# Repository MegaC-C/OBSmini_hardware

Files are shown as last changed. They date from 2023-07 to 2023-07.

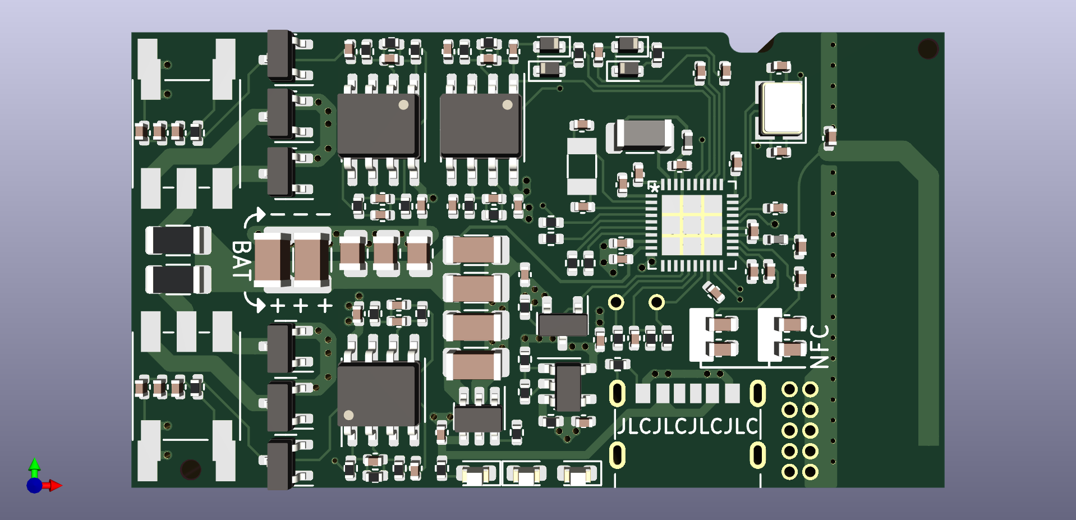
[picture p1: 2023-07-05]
OBSmini_PCB/OBSmini_PCB_TOP.png

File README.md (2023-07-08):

# OBSmini Hardware
This repository includes all the essential PCB and 3D printing files required for the OBSmini hardware.

## PCB

The Bill of Materials (BOM) and layout take inspiration from the reference designs mentioned in the schematic. 
However, they are primarily optimized for availability and cost-effectiveness, particularly for assembly services provided by JLCPCB.

"Basic Parts" are utilized whenever tolerances permit, while "Extended Parts" are employed only when absolutely necessary.

5 PCBs cost 50€ (including parts, assembly and shipping).

[OBSmini_Schematic.pdf](https://github.com/MegaC-C/OBSmini_hardware/files/11957442/OBSmini_PCB.pdf)

OBSmini_PCB_TOP
OBSmini_PCB_BOTTOM

## NFC Antenna PCB

This is simply a PCB antenna tuned to the NFC pins of the nRF52833.

NFC_PCB_antenna

## 3D Printed Case

Fusion 360 Project and three .stl files of OBSmini Case (Top, Spacer, Bottom).



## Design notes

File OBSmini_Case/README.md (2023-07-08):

Fusion 360 Project and three .stl files of OBSmini Case.



.
.
.

(also includes optional solder helper)



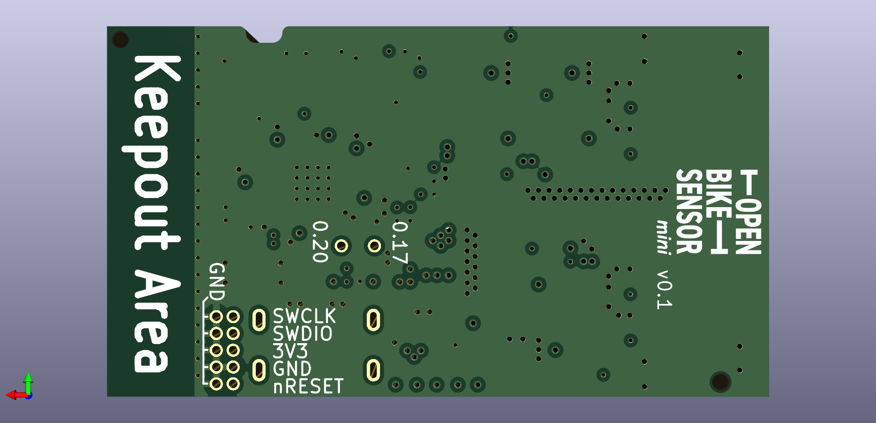
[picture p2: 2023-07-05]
OBSmini_PCB/OBSmini_PCB_BOTTOM.png

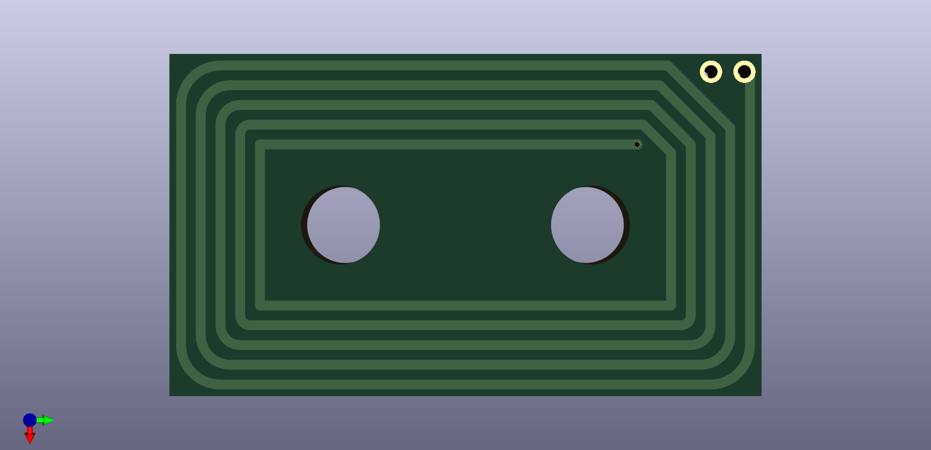
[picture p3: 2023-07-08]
OBSmini_NFC_Antenna_PCB/OBSmini_NFC_Antenna_PCB.png

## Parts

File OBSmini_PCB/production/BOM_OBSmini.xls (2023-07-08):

Comment | Designator | Footprint | JLCPCB Part #
TP4057 | U2 | TSOT-23-6 | C12044
3.3k | R309,R313,R319,R320,R323,R326 | 0402 | C25890
330 | R329 | 0402 | C25104
120k | R318,R325 | 0402 | C25750
4.7k | R303,R304 | 0402 | C25900
10k | R8 | 0402 | C25744
RB521S30T5G | D303,D304,D305,D306 | D_SOD-523 | C896535
10uH | L3 | 1206 | C1051
Q13FC1350000400 | Y2 | Crystal_SMD_3215-2Pin_3.2x1.5mm | C32346
100uF | C304,C305,C323,C324,C325,C333 | 1206 | C15008
68k | R310,R321,R322,R327 | 0402 | C36871
100pFC0G | C18,C19,C21,C22 | 0603 | C14858
USB_C_Receptacle_PowerOnly_6P | J1 | USB_C_SHOU-HAN-TYPE-C-6P | C668623
1pF | C3,C4,C9 | 0402 | C1550
3.9nH | L1 | 0402 | C14033
LED_blue | D4 | 0603 | C72041
AO3401A | Q305 | SOT-23 | C15127
LED_red | D1,D3 | 0603 | C2286
4.7uF | C14,C17,C308,C309,C315,C322,C328,C337,C6 | 0402 | C23733
33k | R305,R306 | 0402 | C25779
47uF | C334,C335,C336 | 0805 | C16780
20pFC0G | C20,C23 | 0402 | C1554
22pF | C314,C320,C327,C332 | 0402 | C1555
12pF | C1,C15,C16,C2 | 0402 | C1547
1.0uF | C12,C13 | 0402 | C52923
X322532MOB4SI | Y1 | Crystal_SMD_3225-4Pin_3.2x2.5mm | C9009
100pF | C10 | 0402 | C1546
1k | R2,R308,R317,R6,R7 | 0402 | C11702
6.8nF | C302,C306,C307,C310,C311,C313,C319,C321 | 0402 | C1542
1 | R301,R302 | 1206 | C17928
AO3400A | Q301,Q302,Q303,Q304 | SOT-23 | C20917
100nF | C11,C26,C5,C7 | 0402 | C307331
2k | R3 | 0402 | C4109
1M | R1,R307,R311,R312,R314,R328 | 0402 | C26083
220pF | C316,C317,C329,C330 | 0402 | C1530
LMV321 | U304 | SOT-23-5 | C7972
1nF | C312,C318,C326,C331,C8 | 0402 | C1523
10nF | C301,C303 | 0402 | C15195
15nH | L4 | 0402 | C27143
MCP6002T | U301,U302,U303 | SOIC-8_3.9x4.9mm_P1.27mm | C7377
20k | R316,R324 | 0402 | C25765
NRF52833-QDAA | U1 | NRF52833-QDAA-R7 | C2895249
BAV99 | D301,D302 | SOT-23 | C2500

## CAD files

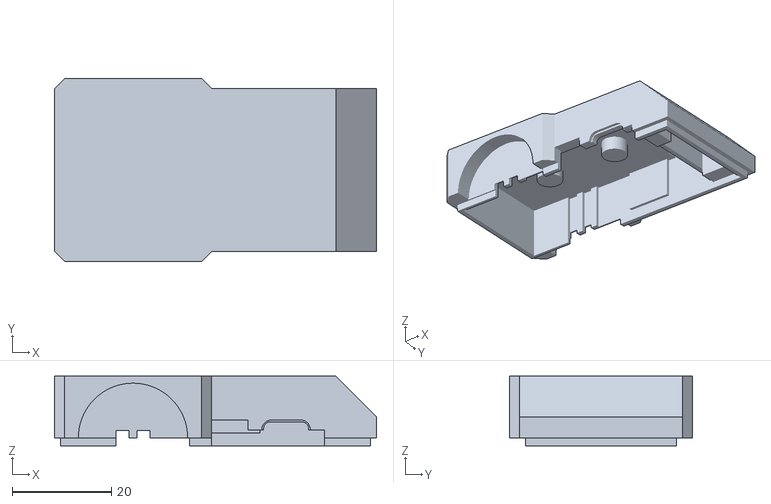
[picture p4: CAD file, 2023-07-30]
OBSmini_Case/OBSmini_Case_Top_with_WindowLED.stl
64.8 x 36.8 x 14.0

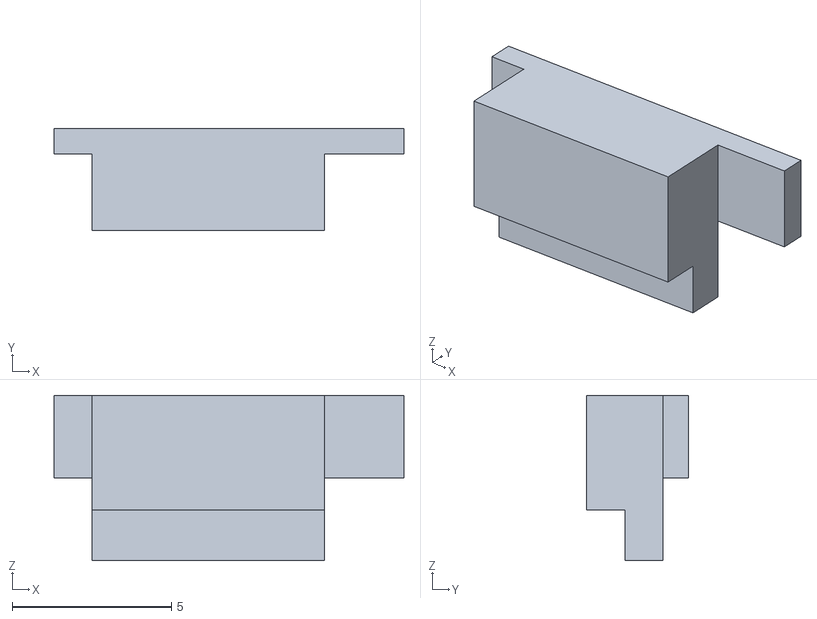
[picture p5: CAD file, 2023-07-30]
OBSmini_Case/OBSmini_Case_WindowLED.stl
11.0 x 3.20 x 5.20

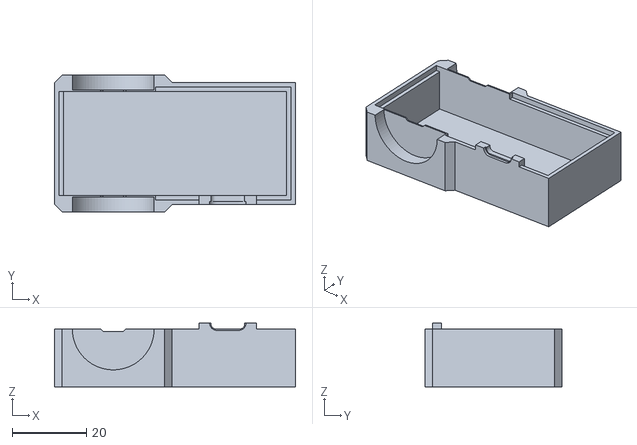
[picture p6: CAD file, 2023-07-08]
OBSmini_Case/OBSmini_Case_Bottom.stl
64.8 x 36.8 x 17.2

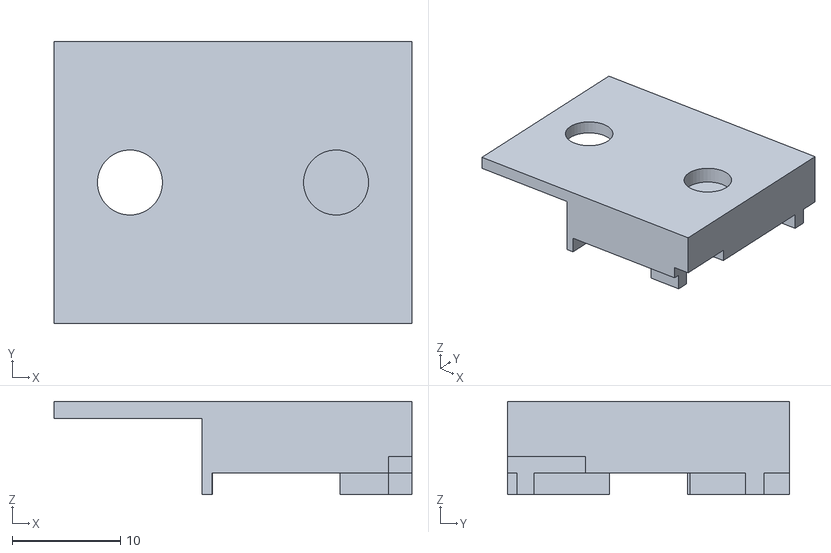
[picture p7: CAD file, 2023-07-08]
OBSmini_Case/OBSmini_Case_Spacer.stl
33.0 x 26.0 x 8.60

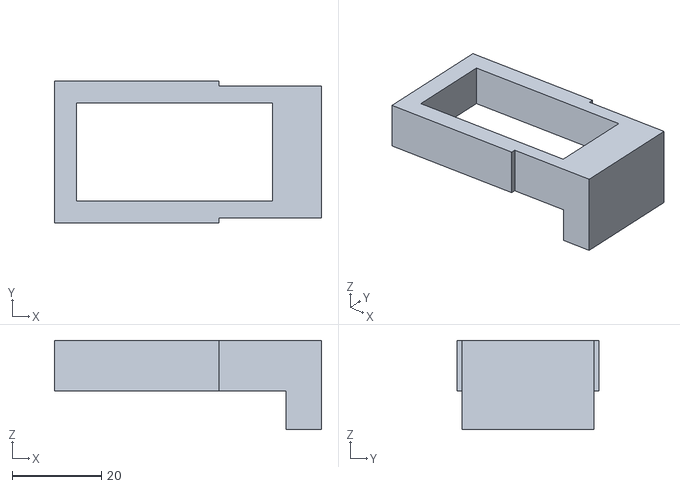
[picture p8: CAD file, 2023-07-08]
OBSmini_Case/OBSmini_solderHelper.stl
60.0 x 32.0 x 20.0

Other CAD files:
OBSmini_Case/OBSmini_Case_Top_without_WindowLED.stl
OBSmini_Case/OBSmini_Case.f3d

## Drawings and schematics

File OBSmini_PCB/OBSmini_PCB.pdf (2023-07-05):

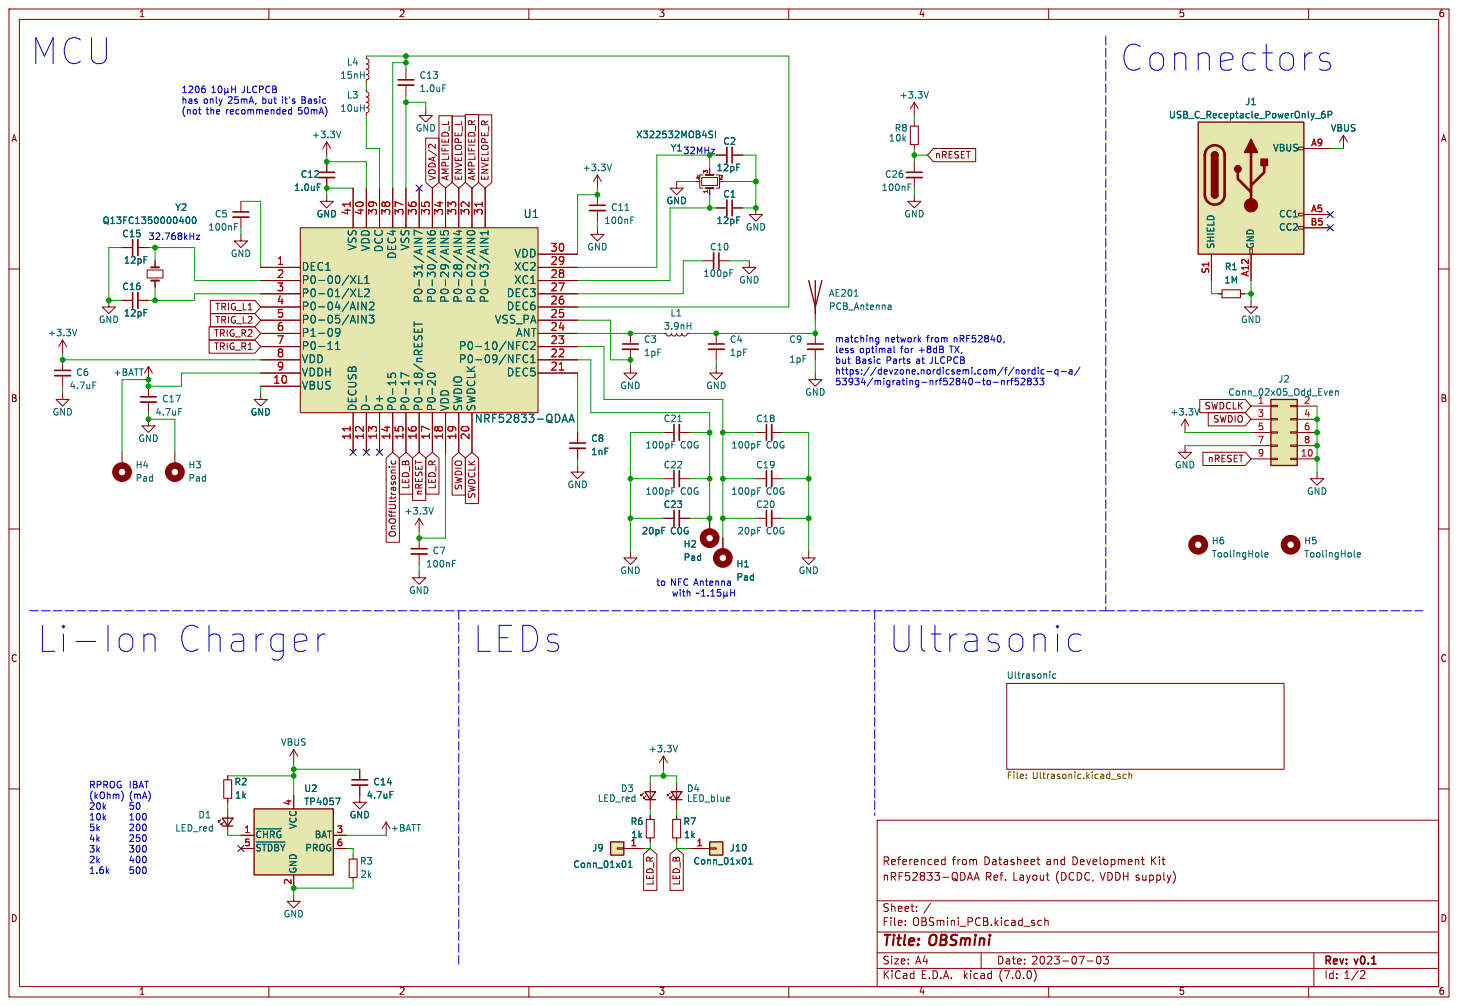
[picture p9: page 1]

32MHz 1206 þÿ10µHJLCPCB
has only 25mA, but it's Basic

matching network from nRF52840,
less optimal for +8dB TX, but Basic Parts at JLCPCB

https://devzone.nordicsemi.com/f/nordic-q-a/

to NFC Antenna with þÿ~1.15µH

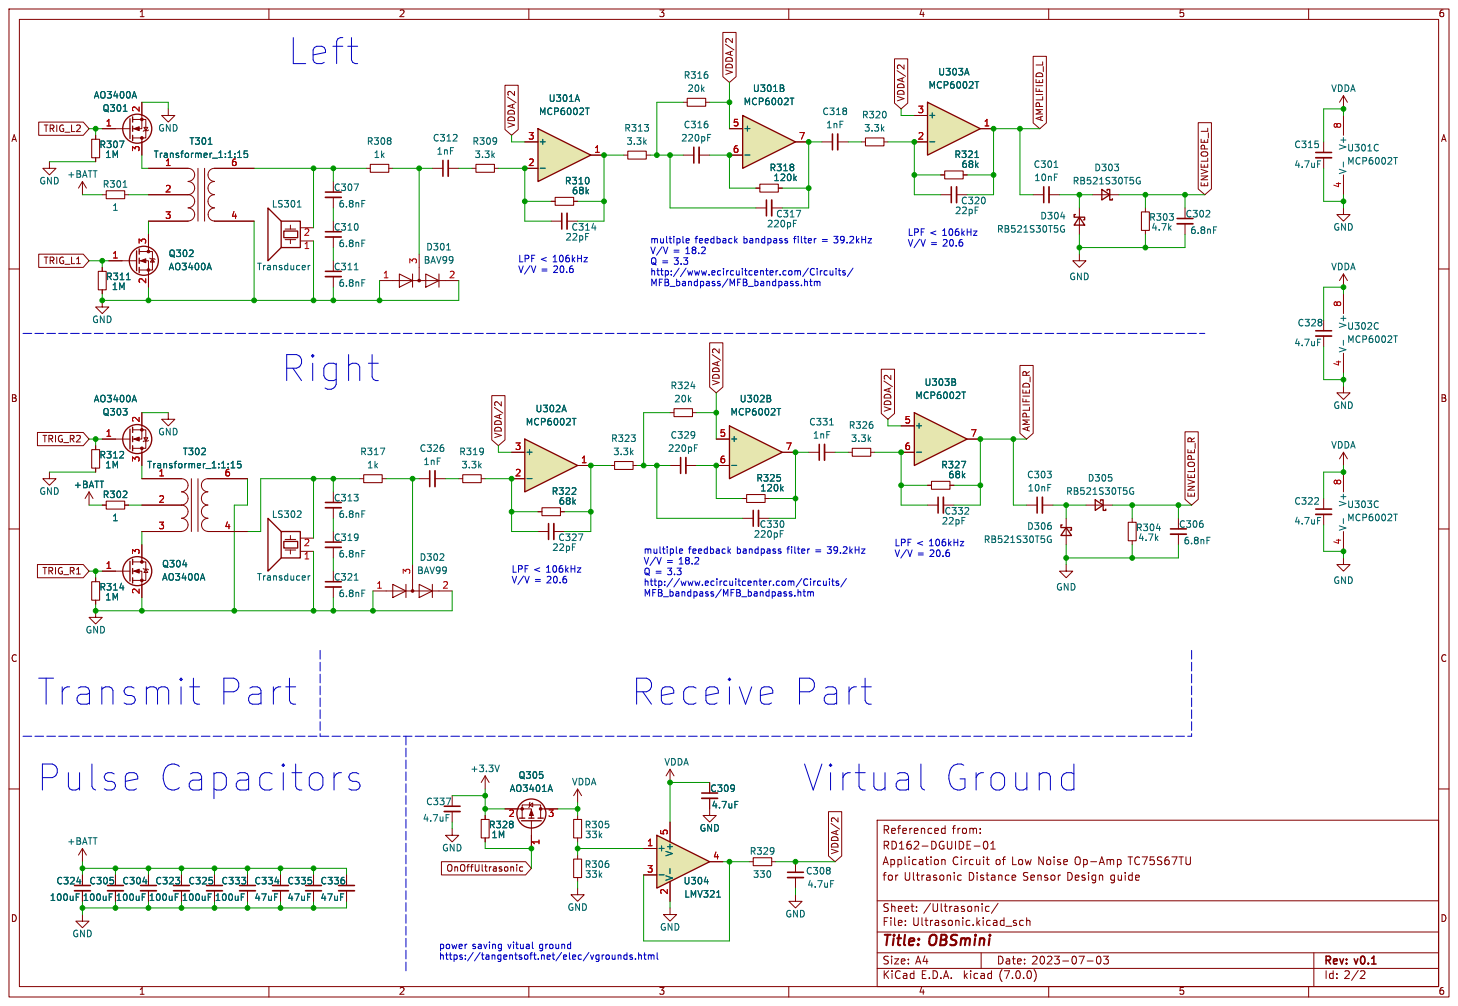
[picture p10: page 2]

http://www.ecircuitcenter.com/Circuits/
MFB_bandpass/MFB_bandpass.htm

Id: 2/2 Title: OBSmini File: Ultrasonic.kicad_sch Sheet: /Ultrasonic/

power saving vitual ground
https://tangentsoft.net/elec/vgrounds.html

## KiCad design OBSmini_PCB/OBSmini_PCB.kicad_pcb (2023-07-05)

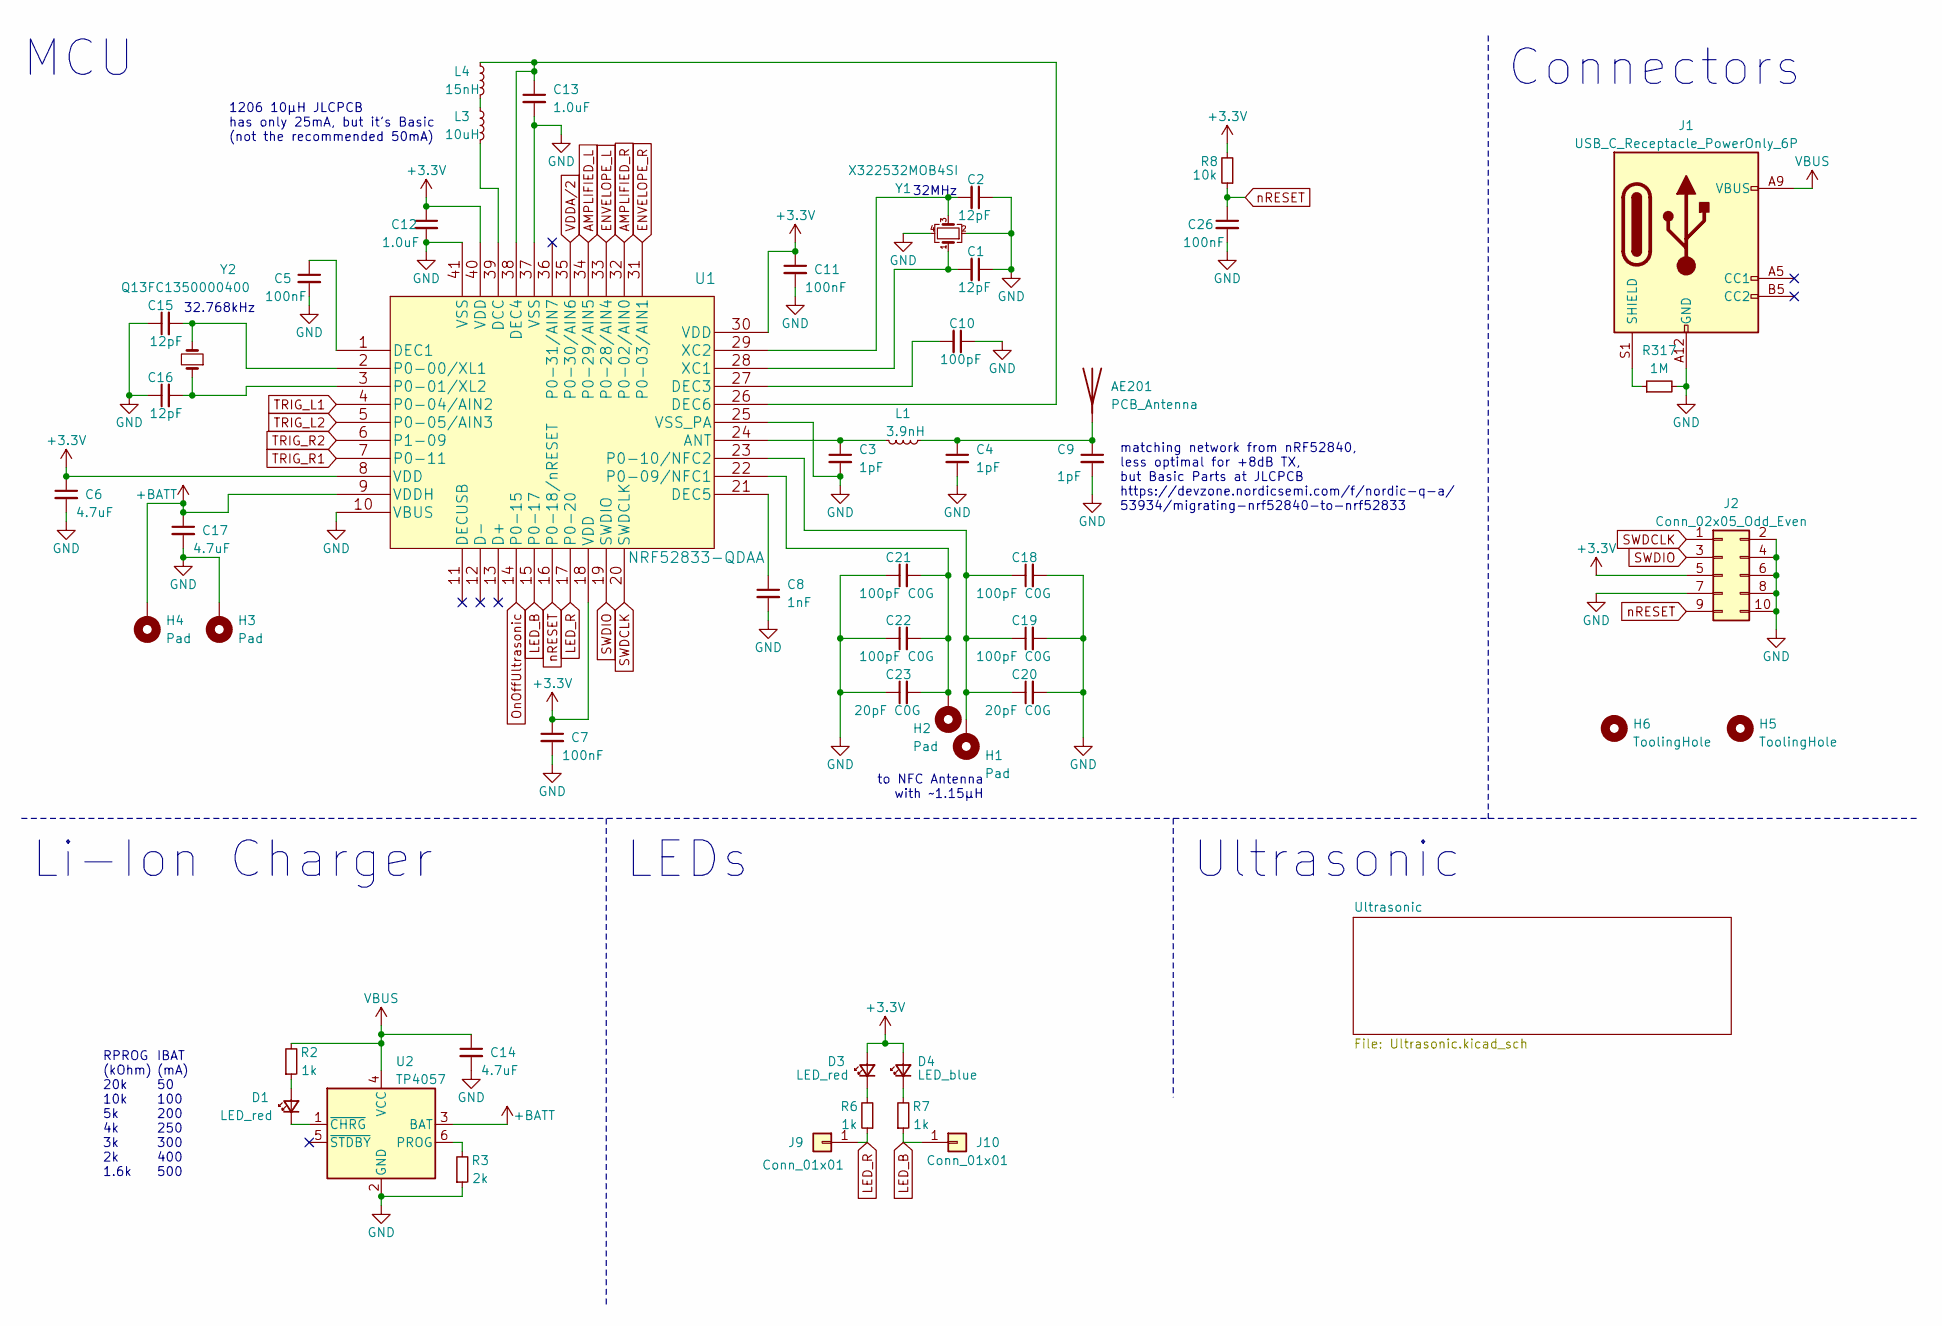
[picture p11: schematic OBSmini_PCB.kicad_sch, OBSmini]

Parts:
AE201: PCB_Antenna; nRF_pcbAntenna
C1, C2, C15, C16: 12pF; C_0402_1005Metric
C3, C4, C9: 1pF; C_0402_1005Metric
C5, C7, C11, C26: 100nF; C_0402_1005Metric
C6, C14, C17: 4.7uF; C_0402_1005Metric
C8: 1nF; C_0402_1005Metric
C10: 100pF; C_0402_1005Metric
C12, C13: 1.0uF; C_0402_1005Metric
C18, C19, C21, C22: 100pF C0G; C_0603_1608Metric
C20, C23: 20pF C0G; C_0402_1005Metric
D1, D3: LED_red; LED_0603_1608Metric
D4: LED_blue; LED_0603_1608Metric
H1, H2, H3, H4: Pad; SolderWirePad_1x01_SMD_1x2mm
H5, H6: ToolingHole; ToolingHoleJLCPCB
J1: USB_C_Receptacle_PowerOnly_6P; USB_C_SHOU-HAN-TYPE-C-6P
J2: Conn_02x05_Odd_Even; PinHeader_2x05_P1.27mm_Vertical
J9, J10: Conn_01x01; PinHeader_1x01_P1.27mm_Vertical
L1: 3.9nH; L_0402_1005Metric
L3: 10uH; L_1206_3216Metric
L4: 15nH; L_0402_1005Metric
R2, R6, R7: 1k; R_0402_1005Metric
R3: 2k; R_0402_1005Metric
R8: 10k; R_0402_1005Metric
R317: 1M; R_0402_1005Metric
U1: NRF52833-QDAA; NRF52833-QDAA-R7
U2: TP4057; TSOT-23-6
Y1: X322532MOB4SI; Crystal_SMD_3225-4Pin_3.2x2.5mm
Y2: Q13FC1350000400; Crystal_SMD_3215-2Pin_3.2x1.5mm

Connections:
+3.3V: C6.1, C7.1, C11.1, C12.1, D3.2 (A), D4.2 (A), J2.5, R8.2, U1.8 (VDD), U1.18 (VDD), U1.30 (VDD), U1.40 (VDD); also elsewhere on the board
+BATT: C17.1, H4.1, U1.9 (VDDH), U2.3 (BAT); also elsewhere on the board
AMPLIFIED_L: U1.34 (P0-29/AIN5); also elsewhere on the board
AMPLIFIED_R: U1.32 (P0-02/AIN0); also elsewhere on the board
ENVELOPE_L: U1.33 (P0-28/AIN4); also elsewhere on the board
ENVELOPE_R: U1.31 (P0-03/AIN1); also elsewhere on the board
LED_B: J10.1, R7.1, U1.15 (P0-17)
LED_R: J9.1, R6.1, U1.17 (P0-20)
unnamed: AE201.1 (A), C4.1, C9.1, L1.1
unnamed: D1.2 (A), R2.1
unnamed: D1.1 (K), U2.1 (~CHRG)
unnamed: D3.1 (K), R6.2
unnamed: D4.1 (K), R7.2
unnamed: L3.1, L4.2
unnamed: C3.1, L1.2, U1.24 (ANT)
unnamed: L3.2, U1.39 (DCC)
unnamed: C5.1, U1.1 (DEC1)
unnamed: C10.2, U1.27 (DEC3)
unnamed: C13.1, L4.1, U1.26 (DEC6), U1.38 (DEC4)
unnamed: C8.1, U1.21 (DEC5)
unnamed: C15.2, U1.2 (P0-00/XL1), Y2.2
unnamed: C16.2, U1.3 (P0-01/XL2), Y2.1
unnamed: C21.2, C22.2, C23.2, H2.1, U1.22 (P0-09/NFC1)
unnamed: C18.1, C19.1, C20.1, H1.1, U1.23 (P0-10/NFC2)
unnamed: C1.2, U1.28 (XC1), Y1.1
unnamed: C2.2, U1.29 (XC2), Y1.3
unnamed: R3.2, U2.6 (PROG)
OnOffUltrasonic: U1.14 (P0-15); also elsewhere on the board
SWDCLK: J2.1, U1.20 (SWDCLK)
SWDIO: J2.3, U1.19 (SWDIO)
TRIG_L1: U1.4 (P0-04/AIN2); also elsewhere on the board
TRIG_L2: U1.5 (P0-05/AIN3); also elsewhere on the board
TRIG_R1: U1.7 (P0-11); also elsewhere on the board
TRIG_R2: U1.6 (P1-09); also elsewhere on the board
VBUS: C14.1, J1.A9 (VBUS), R2.2, U2.4 (VCC)
VDDA/2: U1.35 (P0-30/AIN6); also elsewhere on the board
nRESET: C26.1, J2.9, R8.1, U1.16 (P0-18/nRESET)

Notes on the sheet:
Li-Ion Charger
32.768kHz
32MHz
matching network from nRF52840, less optimal for +8dB TX, but Basic Parts at JLCPCB https://devzone.nordicsemi.com/f/nordic-q-a/ 53934/migrating-nrf52840-to-nrf52833
LEDs
RPROG (kOhm) 20k 10k 5k 4k 3k 2k 1.6k
Connectors
MCU
to NFC Antenna with ~1.15µH
IBAT (mA) 50 100 200 250 300 400 500
1206 10µH JLCPCB has only 25mA, but it's Basic (not the recommended 50mA)
Ultrasonic

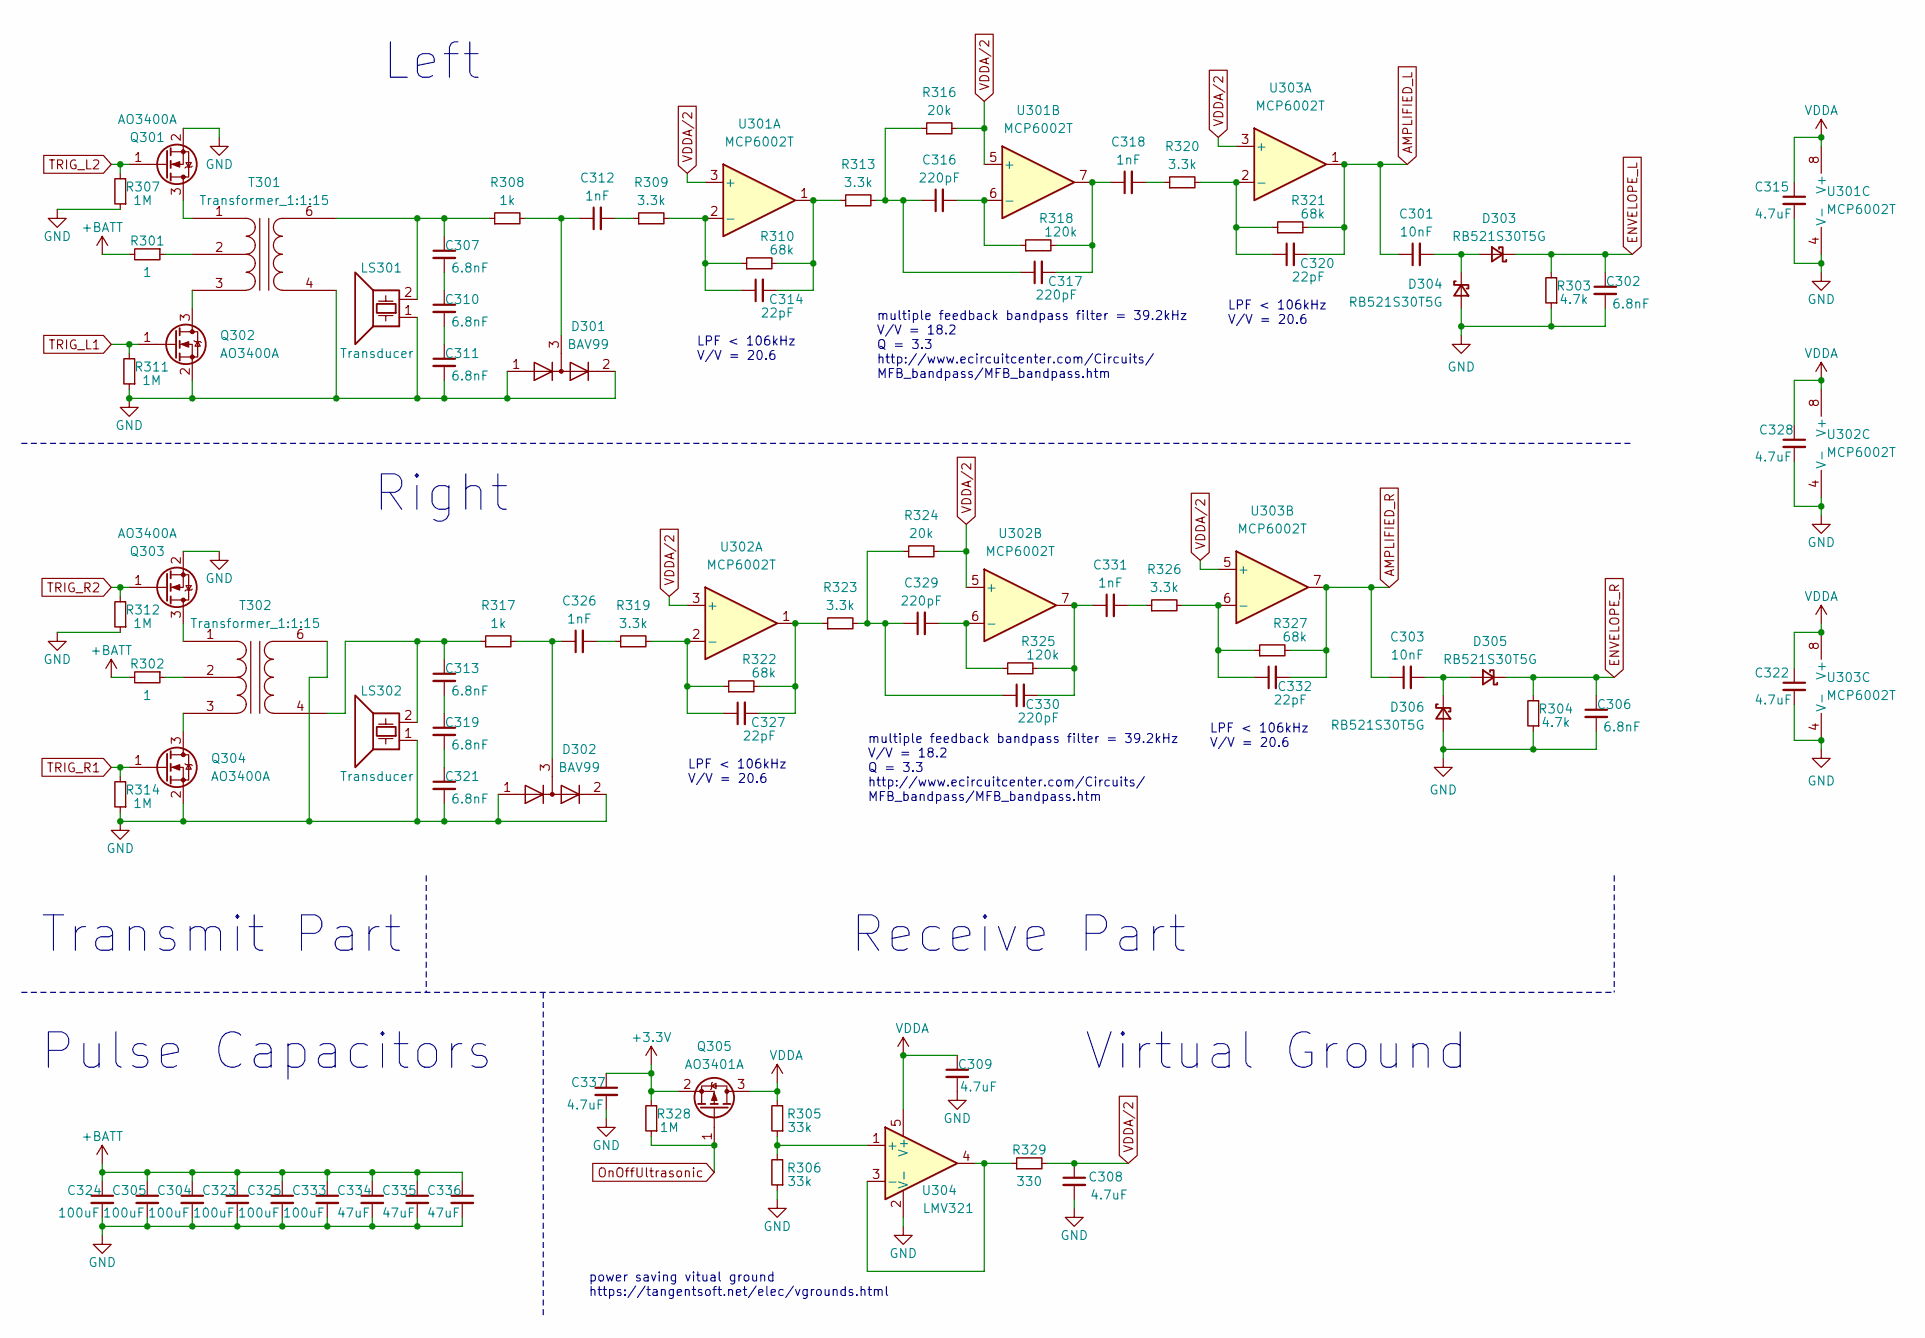
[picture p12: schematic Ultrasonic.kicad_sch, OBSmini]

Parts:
C301, C303: 10nF; C_0402_1005Metric
C302, C306, C307, C310, C311, C313, C319, C321: 6.8nF; C_0402_1005Metric
C304, C305, C323, C324, C325, C333: 100uF; C_1206_3216Metric
C308, C309, C315, C322, C328, C337: 4.7uF; C_0402_1005Metric
C312, C318, C326, C331: 1nF; C_0402_1005Metric
C314, C320, C327, C332: 22pF; C_0402_1005Metric
C316, C317, C329, C330: 220pF; C_0402_1005Metric
C334, C335, C336: 47uF; C_0805_2012Metric
D301, D302: BAV99; SOT-23
D303, D304, D305, D306: RB521S30T5G; D_SOD-523
LS301, LS302: Transducer; Transducer@Transformer
Q301, Q302, Q303, Q304: AO3400A; SOT-23
Q305: AO3401A; SOT-23
R301, R302: 1; R_1206_3216Metric
R303, R304: 4.7k; R_0402_1005Metric
R305, R306: 33k; R_0402_1005Metric
R307, R311, R312, R314, R328: 1M; R_0402_1005Metric
R308, R317: 1k; R_0402_1005Metric
R309, R313, R319, R320, R323, R326: 3.3k; R_0402_1005Metric
R310, R321, R322, R327: 68k; R_0402_1005Metric
R316, R324: 20k; R_0402_1005Metric
R318, R325: 120k; R_0402_1005Metric
R329: 330; R_0402_1005Metric
T301, T302: Transformer_1:1:15; B78416A2430A003
U301, U302, U303: MCP6002T; SOIC-8_3.9x4.9mm_P1.27mm
U304: LMV321; SOT-23-5

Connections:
+3.3V: C337.1, Q305.2 (S), R328.2; also elsewhere on the board
+BATT: C304.1, C305.1, C323.1, C324.1, C325.1, C333.1, C334.1, C335.1, C336.1, R301.2, R302.2; also elsewhere on the board
AMPLIFIED_L: C301.1, C320.2, R321.2, U303.1; also elsewhere on the board
AMPLIFIED_R: C303.1, C332.2, R327.2, U303.7; also elsewhere on the board
ENVELOPE_L: C302.1, D303.1 (K), R303.2; also elsewhere on the board
ENVELOPE_R: C306.1, D305.1 (K), R304.2; also elsewhere on the board
unnamed: C307.2, C310.1
unnamed: C310.2, C311.1
unnamed: C312.1, D301.3 (K), R308.2
unnamed: C312.2, R309.1
unnamed: C313.2, C319.1
unnamed: C314.2, R310.2, R313.1, U301.1
unnamed: C316.1, C317.1, R313.2, R316.1
unnamed: C317.2, C318.1, R318.2, U301.7
unnamed: C318.2, R320.1
unnamed: C319.2, C321.1
unnamed: C326.2, R319.1
unnamed: C327.2, R322.2, R323.1, U302.1
unnamed: C329.1, C330.1, R323.2, R324.1
unnamed: C330.2, C331.1, R325.2, U302.7
unnamed: C331.2, R326.1
unnamed: C301.2, D303.2 (A), D304.1 (K)
unnamed: C303.2, D305.2 (A), D306.1 (K)
unnamed: Q301.3 (D), T301.1 (PR1)
unnamed: Q302.3 (D), T301.3 (PR2)
unnamed: Q303.3 (D), T302.1 (PR1)
unnamed: Q304.3 (D), T302.3 (PR2)
unnamed: R301.1, T301.2 (PM)
unnamed: C307.1, LS301.2, R308.1, T301.6 (S2)
unnamed: R302.1, T302.2 (PM)
unnamed: C314.1, R309.2, R310.1, U301.2 (-)
unnamed: C316.2, R318.1, U301.6 (-)
unnamed: C327.1, R319.2, R322.1, U302.2 (-)
unnamed: C329.2, R325.1, U302.6 (-)
unnamed: C320.1, R320.2, R321.1, U303.2 (-)
unnamed: C332.1, R326.2, R327.1, U303.6 (-)
unnamed: R305.1, R306.2, U304.1 (+)
unnamed: R329.1, U304.3 (-), U304.4
OnOffUltrasonic: Q305.1 (G), R328.1; also elsewhere on the board
TRIG_L1: Q302.1 (G), R311.2; also elsewhere on the board
TRIG_L2: Q301.1 (G), R307.2; also elsewhere on the board
TRIG_R1: Q304.1 (G), R314.2; also elsewhere on the board
TRIG_R2: Q303.1 (G), R312.2; also elsewhere on the board
VDDA: C309.1, C315.1, C322.1, C328.1, Q305.3 (D), R305.2, U301.8 (V+), U302.8 (V+), U303.8 (V+), U304.5 (V+)
VDDA/2: C308.1, R316.2, R324.2, R329.2, U301.3 (+), U301.5 (+), U302.3 (+), U302.5 (+), U303.3 (+), U303.5 (+); also elsewhere on the board

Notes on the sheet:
Pulse Capacitors
multiple feedback bandpass filter = 39.2kHz V/V = 18.2 Q = 3.3 http://www.ecircuitcenter.com/Circuits/ MFB_bandpass/MFB_bandpass.htm
LPF < 106kHz V/V = 20.6
Receive Part
Transmit Part
Virtual Ground
Left
power saving vitual ground https://tangentsoft.net/elec/vgrounds.html
Right

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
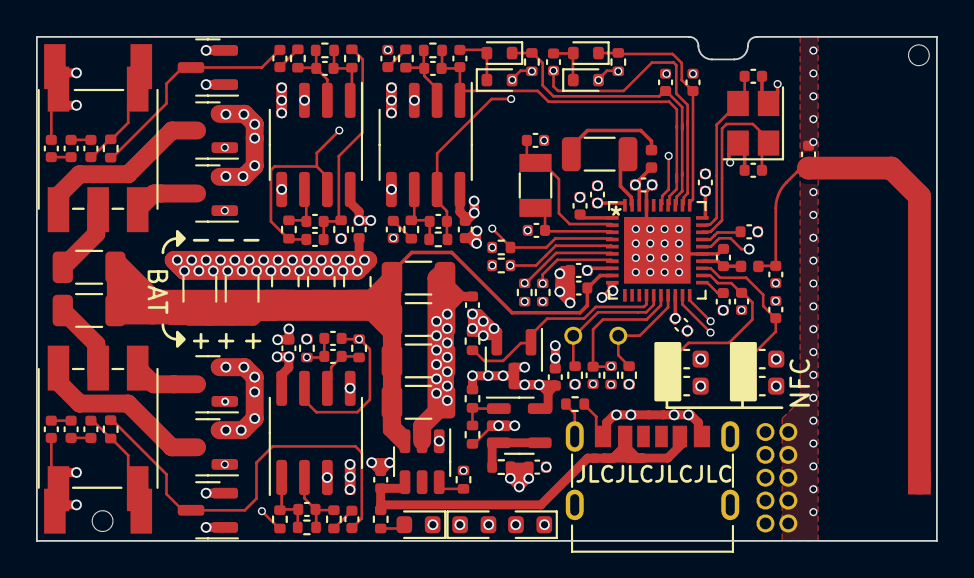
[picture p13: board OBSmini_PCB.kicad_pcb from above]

Board: 6 copper layers, 50.0 x 28.0 mm, 135 parts (0 on the bottom side), 74 nets.

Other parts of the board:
R1: 1M; R_0402_1005Metric

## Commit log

2023-07-03 First Commit
    must be revised
    [Ultrasonic.kicad_sch, UltrasonicNRF52mini.kicad_pcb, UltrasonicNRF52mini.kicad_sch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]
2023-07-03 added schematic
2023-07-05 added project libraries
    [OBSmini_PCB.kicad_pcb, OBSmini_PCB.kicad_sch, Ultrasonic.kicad_sch]
2023-07-08 not sure if .f3d is the correct file
    [OBSmini_Case.f3d, OBSmini_Case_Bottom.stl, OBSmini_Case_Spacer.stl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]
2023-07-08 added production files
    [BOM_OBSmini.xls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]
2023-07-30 added window LED case
    [OBSmini_Case.f3d, OBSmini_Case_Top_with_WindowLED.stl, OBSmini_Case_Top_without_WindowLED.stl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]
